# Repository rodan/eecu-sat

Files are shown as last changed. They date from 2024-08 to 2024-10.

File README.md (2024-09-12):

<a href="https://scan.coverity.com/projects/rodan-eecu-sat">
  
</a>

## eecu-sat (Engine ECU signal acquisition tool)

set of multiple modules that allow all analog signals generated and received by a vehicle's Engine Electronic Control Unit to be captured and analyzed. it can either be used as a testing jig for EECUs or as a low level diagnostic tool in which a known good set of signals can be used as reference.

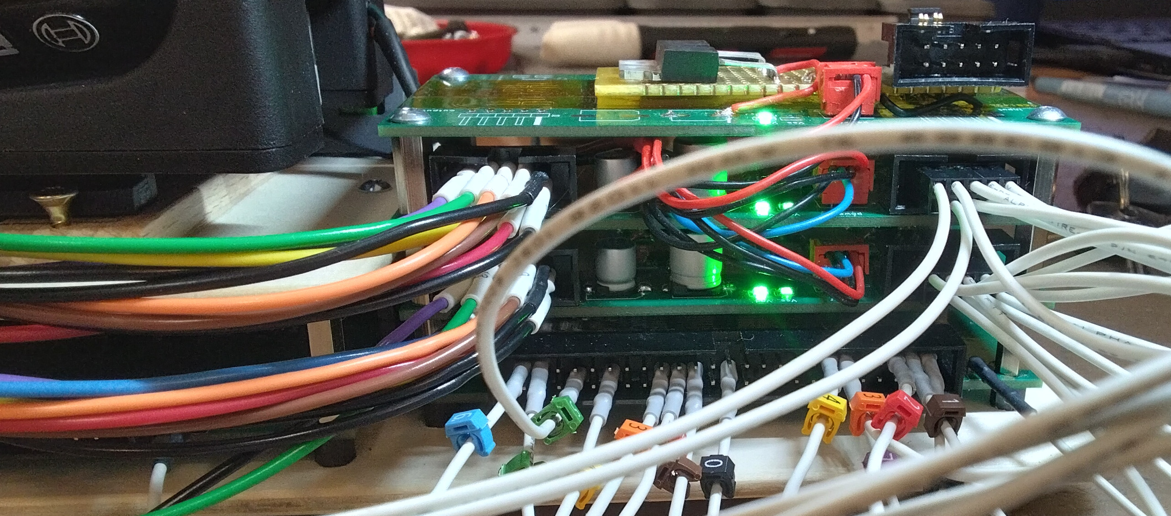
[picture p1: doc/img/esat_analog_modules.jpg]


a number of filters and buffers are used to protect the ADCs from transient spikes generated by all inductive loads

```
 source:       https://github.com/rodan/eecu-sat
 author:       Petre Rodan <2b4eda@subdimension.ro>
 license:      GNU GPLv3

 software architecture based on libsigrok and sigrok-cli
 source:       https://sigrok.org
 author:       Bert Vermeulen
 license:      GNU GPLv3
```

more images of the prototype in action are available [here](https://photos.app.goo.gl/Gay5FS8gsCTZkYcH9)

## Project components

project directory structure

 * ./hardware/buffy - kicad based schematics and pcbs for the analog buffer stage
 * ./hardware/pb\_jst-zro*  - kicad based schematics and pcbs for the proxy boards that intercept all EECU signals for a KTM 1090 EECU that uses JST ZRO 36 and 48 pin connectors
 * ./ltspice - spice simulation of the analog buffer schematic
 * ./software/eecu-sat - program that processes the raw analog data exported by [Saleae's Logic](https://www.saleae.com/pages/downloads) and converts them into [sigrok](https://sigrok.org/wiki/File_format:Sigrok/v2) files
 * .doc/ktm\_1090\_wiring.ods - ktm 1090 ECU pinout based on wire harness specs present in the service manual

## eecu-sat software

The software's code is shaped around the [sigrok](https://sigrok.org) library which is a great open-source signal analysis suite. I would have preferred to simply patch libsigrok and sigrok-cli to support the functionality that was needed for this project, however things did not go that smoothly. AFAICT libsigrok assumes that all input signals formats are interlaced, which makes sense from an acquisition system standpoint - samples are usually read by a single thread by switching channels in a loop. so CH1\_sample, CH2\_sample ... CH16\_sample, CH1\_sample, CH2\_sample ... in a row. Also it only supports single-file inputs. Quoting a libsigrok source file,

```
Saleae Logic applications typically export one file per channel. The sigrok
input modules exclusively handle an individual file, existing applications
may not be prepared to handle a set of files, or handle "special" file types
like directories. Some of them will even actively reject such input specs.
Merging multiple exported channels into either another input file or a sigrok
session is supposed to be done outside of this input module.
```

This is the reason why the code is basically a fork of sigrok-cli that contains my own input, output and transform modules that treat all samples in a non-interlaced manner.

### Build requirements

#### Linux
Notable dependencies would be a gcc, make, libzip and the libsigrok headers.

```
cd ./software/eecu-sat
make
```

#### FreeBSD

this is 'Work in progress', not functional just yet. dependencies: gcc13, gmake, gsed

```
export CC='/usr/local/bin/gcc13'
cd ./software/eecu-sat
gmake
```

### Usage

a manual is provided
```
man ./doc/eecu-sat.1
```

***SYNOPSIS***

eecu-sat [-hv] [-i, --input FILENAME_MATCH ] [-o, --output FILE\_PREFIX] [-O, --output-format OUTPUT ] [-t, --triggers TRIGGERS ] [-T, --transform-module TRANSFORM ] [-L, --list]

### TODO list (In Progress)

- [ ] analyze all 48 channels and automatically detect faults based on a known good reference capture
- [x] synchronize multiple sets of 16 channel acquisitions into one 48 channel srzip file
- [x] crop intervals in a signal, based on a trigger definition
- [x] convert Logic exported raw analog signals into srzip files that can be loaded in pulseview
- [x] relabeling capability of channels when seen in pulseview
- [x] 3-point calibration of all analog channels
  - [x] use ini file to input calibration paramenters
  - [x] analyze analog calibration signals, detect the calibration points
  - [x] apply acceptance criteria to input calibration signal
  - [x] export slopes and offsets into calibration ini file

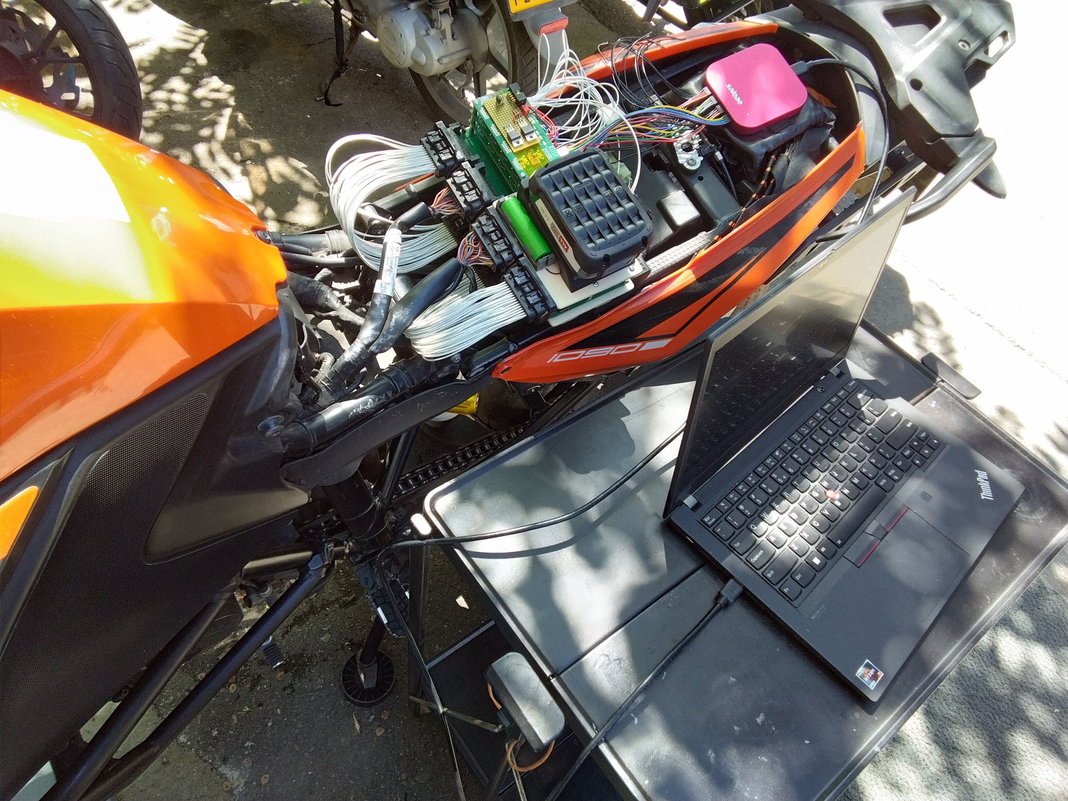
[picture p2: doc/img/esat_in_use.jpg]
tool in use


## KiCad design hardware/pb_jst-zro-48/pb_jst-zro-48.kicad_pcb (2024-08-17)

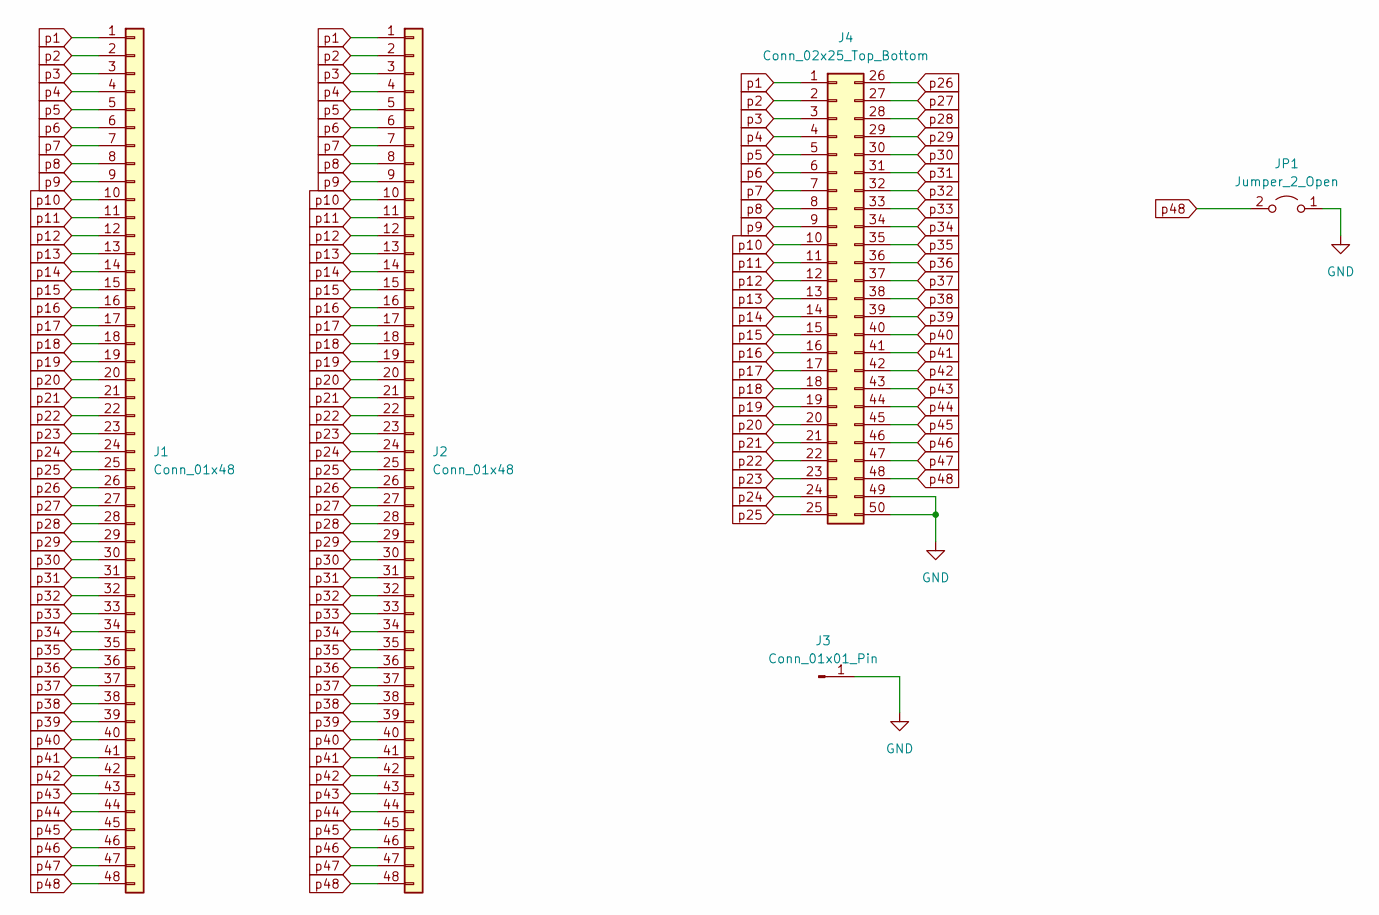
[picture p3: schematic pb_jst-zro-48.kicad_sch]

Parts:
J1, J2: Conn_01x48; S48B-ZROK-2A
J3: Conn_01x01_Pin; PinHeader_1x01_P2.54mm_Horizontal
J4: Conn_02x25_Top_Bottom; PinHeader_2x25_P2.54mm_Horizontal
JP1: Jumper_2_Open; PinHeader_1x02_P2.54mm_Vertical

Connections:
GND: J3.1, J4.49, J4.50, JP1.1 (A)
p1: J1.1, J2.1, J4.1
p2: J1.2, J2.2, J4.2
p3: J1.3, J2.3, J4.3
p4: J1.4, J2.4, J4.4
p5: J1.5, J2.5, J4.5
p6: J1.6, J2.6, J4.6
p7: J1.7, J2.7, J4.7
p8: J1.8, J2.8, J4.8
p9: J1.9, J2.9, J4.9
p10: J1.10, J2.10, J4.10
p11: J1.11, J2.11, J4.11
p12: J1.12, J2.12, J4.12
p13: J1.13, J2.13, J4.13
p14: J1.14, J2.14, J4.14
p15: J1.15, J2.15, J4.15
p16: J1.16, J2.16, J4.16
p17: J1.17, J2.17, J4.17
p18: J1.18, J2.18, J4.18
p19: J1.19, J2.19, J4.19
p20: J1.20, J2.20, J4.20
p21: J1.21, J2.21, J4.21
p22: J1.22, J2.22, J4.22
p23: J1.23, J2.23, J4.23
p24: J1.24, J2.24, J4.24
p25: J1.25, J2.25, J4.25
p26: J1.26, J2.26, J4.26
p27: J1.27, J2.27, J4.27
p28: J1.28, J2.28, J4.28
p29: J1.29, J2.29, J4.29
p30: J1.30, J2.30, J4.30
p31: J1.31, J2.31, J4.31
p32: J1.32, J2.32, J4.32
p33: J1.33, J2.33, J4.33
p34: J1.34, J2.34, J4.34
p35: J1.35, J2.35, J4.35
p36: J1.36, J2.36, J4.36
p37: J1.37, J2.37, J4.37
p38: J1.38, J2.38, J4.38
p39: J1.39, J2.39, J4.39
p40: J1.40, J2.40, J4.40
p41: J1.41, J2.41, J4.41
p42: J1.42, J2.42, J4.42
p43: J1.43, J2.43, J4.43
p44: J1.44, J2.44, J4.44
p45: J1.45, J2.45, J4.45
p46: J1.46, J2.46, J4.46
p47: J1.47, J2.47, J4.47
p48: J1.48, J2.48, J4.48, JP1.2 (B)

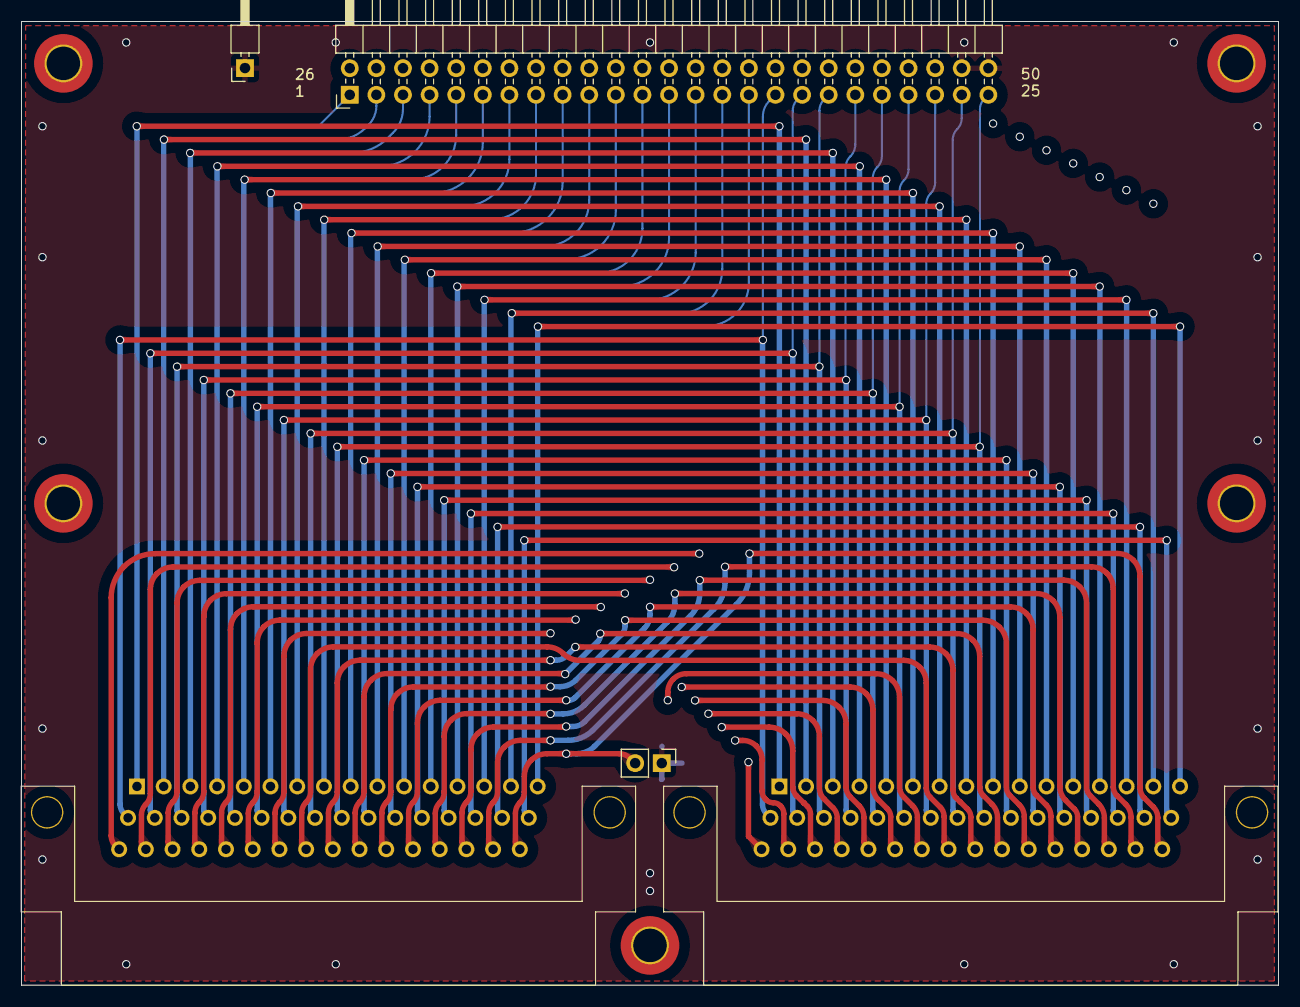
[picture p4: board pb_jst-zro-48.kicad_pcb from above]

Board: 4 copper layers, 120.0 x 92.0 mm, 5 parts (0 on the bottom side), 49 nets.

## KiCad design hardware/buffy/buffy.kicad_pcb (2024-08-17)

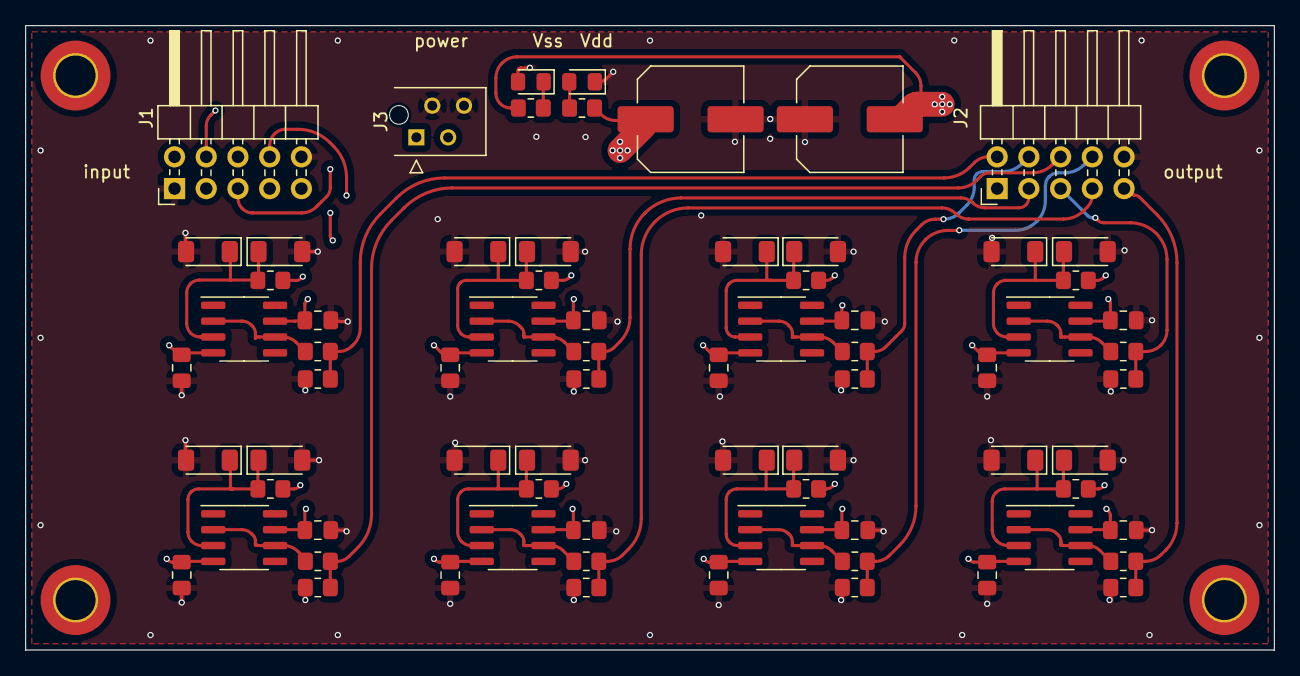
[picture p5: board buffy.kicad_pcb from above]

Board: 4 copper layers, 100.0 x 50.0 mm, 73 parts (0 on the bottom side), 37 nets.

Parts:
C1, C2: 220u; C_Elec_8x10.2
C102, C103, C112, C113, C122, C123, C132, C133, C142, C143, C152, C153, C162, C163, C172, C173: 100n; C_0805_2012Metric_Pad1.18x1.45mm_HandSolder
D1, D2: LED; LED_0805_2012Metric_Pad1.15x1.40mm_HandSolder
D101, D111, D121, D131, D141, D151, D161, D171: TZMB15-GS08; D_MiniMELF
D102, D112, D122, D132, D142, D152, D162, D172: BZV55B15; D_MiniMELF
J1, J2: Conn_02x05_Odd_Even; PinHeader_2x05_P2.54mm_Horizontal
J3: Conn_01x04_Pin; TE_Micro-MaTch_215079-4_2x02_P1.27mm_Vertical
R1, R2: 100k; R_0805_2012Metric_Pad1.20x1.40mm_HandSolder
R101, R111, R121, R131, R141, R151, R161, R171: 10K; R_0805_2012Metric_Pad1.20x1.40mm_HandSolder
R105, R115, R125, R135, R145, R155, R165, R175: 5K 0.1%; R_0805_2012Metric_Pad1.20x1.40mm_HandSolder
R106, R116, R126, R136, R146, R156, R166, R176: 10K 0.1%; R_0805_2012Metric_Pad1.20x1.40mm_HandSolder
U101, U111, U121, U131, U141, U151, U161, U171: OPA140; SOIC-8_3.9x4.9mm_P1.27mm

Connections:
GND: C1.2, C2.1, C102.2, C103.1, C112.2, C113.1, C122.2, C123.1, C132.2, C133.1, C142.2, C143.1, C152.2, C153.1, C162.2, C163.1, C172.2, C173.1, D1.1 (K), D2.2 (A), D101.2 (A), D102.2 (A), D111.2 (A), D112.2 (A), D121.2 (A), D122.2 (A), D131.2 (A), D132.2 (A), D141.2 (A), D142.2 (A), D151.2 (A), D152.2 (A), D161.2 (A), D162.2 (A), D171.2 (A), D172.2 (A), J1.1, J1.10, J2.1, J2.10, J3.2, J3.4, R106.2, R116.2, R126.2, R136.2, R146.2, R156.2, R166.2, R176.2
unnamed: D1.2 (A), R1.2
unnamed: D2.1 (K), R2.2
unnamed: D101.1 (K), D102.1 (K), R101.1, U101.3 (+)
unnamed: D111.1 (K), D112.1 (K), R111.1, U111.3 (+)
unnamed: D121.1 (K), D122.1 (K), R121.1, U121.3 (+)
unnamed: D131.1 (K), D132.1 (K), R131.1, U131.3 (+)
unnamed: D141.1 (K), D142.1 (K), R141.1, U141.3 (+)
unnamed: D151.1 (K), D152.1 (K), R151.1, U151.3 (+)
unnamed: D161.1 (K), D162.1 (K), R161.1, U161.3 (+)
unnamed: D171.1 (K), D172.1 (K), R171.1, U171.3 (+)
unnamed: R105.1, U101.2 (-), U101.6
unnamed: R115.1, U111.2 (-), U111.6
unnamed: R125.1, U121.2 (-), U121.6
unnamed: R135.1, U131.2 (-), U131.6
unnamed: R145.1, U141.2 (-), U141.6
unnamed: R155.1, U151.2 (-), U151.6
unnamed: R165.1, U161.2 (-), U161.6
unnamed: R175.1, U171.2 (-), U171.6
VDD: C1.1, C102.1, C112.1, C122.1, C132.1, C142.1, C152.1, C162.1, C172.1, J3.1, R1.1, U101.7 (V+), U111.7 (V+), U121.7 (V+), U131.7 (V+), U141.7 (V+), U151.7 (V+), U161.7 (V+), U171.7 (V+)
VSS: C2.2, C103.2, C113.2, C123.2, C133.2, C143.2, C153.2, C163.2, C173.2, J3.3, R2.1, U101.4 (V-), U111.4 (V-), U121.4 (V-), U131.4 (V-), U141.4 (V-), U151.4 (V-), U161.4 (V-), U171.4 (V-)
in0: J1.2, R101.2
in1: J1.3, R111.2
in2: J1.4, R121.2
in3: J1.5, R131.2
in4: J1.6, R141.2
in5: J1.7, R151.2
in6: J1.8, R161.2
in7: J1.9, R171.2
out0: J2.2, R105.2, R106.1
out1: J2.3, R115.2, R116.1
out2: J2.4, R125.2, R126.1
out3: J2.5, R135.2, R136.1
out4: J2.6, R145.2, R146.1
out5: J2.7, R155.2, R156.1
out6: J2.8, R165.2, R166.1
out7: J2.9, R175.2, R176.1

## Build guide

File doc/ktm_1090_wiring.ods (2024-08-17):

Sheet: A10 - central electronics control unit
CO/34 X1
1 | wh-bl | radiator fans
2 | bl-gr | rear right turn signal
3 | bl-gn | radiator fans
4 | or-bl | right signal switch
5 | gn-ye | break/tail light
6 | ye | license plate light
8 | bl-pu | stop signal switch
9 | pk-ye | front brake light switch
10 | bl | turn signal front right
11 | br | GND?
12 | bu-gr | connector, A11.26
13 | pu-or | left signal switch
14 | pu-gn | hazard switch
15 | rd-gr | horn switch
17 | pk-br | rear break light switch
18 | pu | turn signal front left
19 | br | GND?
20 | rd-pu | alarm system
22 | gn-pk | connector X100.1, 8.F1 o
23 | gn-gr | connector X100.7, 8.F1 p
25 | rd-gr | high beam switch
24 | gn | connector, A11.25
26 | bl-bu | fuel pump
27 | gr-pu | turn signal rear left
28 | bu-br | fuel pump
30 | wh-gn | break/tail light
31 | wh-rd | 12V?
33 | wh-rd | ACC2 12V out
A0/26 X2
1 | wh | parking light/daytime running light
3 | ye-rd | connector X100.8, A11.1/48
4 | gn-rd | q 5.F8
5 | or | evaporate emissions control valve
6 | lbu | tip switch
7 | gn | low beam
8 | bl-rd | starter relay 30A fuse 12V out
9 | bl-br | 6.F8 j, connector X100.6, 8.F1 j
10 | wh-bl | connector X100.12, A11.31/48
11 | or | evaporate emissions control valve
12 | wh-bu | CAN L, 5.B8 l, connector X100.10
13 | bl-bu | CAN H, 5.B8 h, connector X100.9
14 | gr | horn
15 | br-rd | fuel level sensor
16 | br-gn | connector X100.16, 8.F1 t
17 | wh-rd | voltage regulator 12V out
18 | rd | ignition/steering lock
19 | wh-rd | F2 10A fuse ACC1 12V out
20 | bu | high beam
21 | bl-br | combination switch common
22 | wh-ye | parking light/daytime running light
23 | wh-gr | emergency OFF
24 | br | GND?
25 | bl-ye | GND?
26 | ye-or | heated grip connector

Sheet: A11 - Engine electronics control unit
GF/48 |  |  | sequence | channel | aq channel
1 | ye-rd | connector X100.8, A10.3/26 | 1 | 0 | 0 0
2 | lbu | lambda sensor, cylinder 1 (heater) | 3 | 0 | 0 0
3 | or-pk | lambda sensor, cylinder 2 (heater) | 3 | 1 | 0 1
6 | bl-or | connector X100.15, evaporate emission control valve | 1 | 1 | 0 1
7 | wh-rd | SAS valve | 1 | 2 | 0 2
8 | br | GND
13 | br | GND
14 | wh-pu | ignition coil 1, cylinder 1 | 3 | 2 | 0 2
15 | wh-br | ignition coil 1, cylinder 2 | 3 | 3 | 0 3
16 | ye-pu | ignition coil 2, cylinder 1 | 3 | 4 | 0 4
17 | bu-pu | accelerator position sensor circuit A/B (bus) | 1 | 3 | 0 3
18 | bl | sensors common | 1 | 4 | 0 4
19 | bl-pk | tps? bus | 1 | 5 | 0 5
20 | ye-or | tps? | 1 | 6 | 0 6
21 | pu-gn | accelerator position sensor circuit A/B | 1 | 7 | 0 7
23 | br-gn | gear position sensor pin4 | 1 | 8 | 1 0
24 | wh | connector X100.3, 6.F8 i | 3 | 5 | 0 5
25 | gn | connector X100.5, A10.24/34 | 3 | 6 | 0 6
26 | wh-or | tps? | 1 | 9 | 1 1
27 | wh-gr | gear position sensor pin1 | 1 | 10 | 1 2
28 | gn-pk | accelerator position sensor circuit A/B | 1 | 11 | 1 3
31 | wh-bl | connector X100.12, A10.10/26 | 1 | 12 | 1 4
32 | ye-br | ignition coil 2, cylinder 2 | 3 | 7 | 0 7
33 | bu-pk | tps? bus | 1 | 13 | 1 5
34 | bu | sensors common | 2 | 0 | 0 0
35 | bl-pu | accelerator position sensor circuit A/B (bus) | 2 | 1 | 0 1
36 | pu | induction manifold pressure sensor cylinder 1 | 3 | 8 | 1 0
37 | gr-pu | induction manifold pressure sensor cylinder 2 | 3 | 9 | 1 1
38 | ye-gn | rollover sensor | 2 | 2 | 0 2
40 | bl-ye | coolant temperature sensor cylinder 1 | 2 | 3 | 0 3
41 | gn-gr | ambient air pressure sensor | 2 | 4 | 0 4
42 | rd | intake air temperature sensor | 2 | 5 | 0 5
45 | ye | connector X100.11, clutch switch | 2 | 6 | 0 6
47 | pk | side stand sensor | 2 | 7 | 0 7
48 | br | GND
GG/36 | jst k-d
1 | or | connector X100.4 X100.14, A10.5/26 A10.11/26 | 2 | 8 | 1 0
2 | gn-or | throttle stepper motor pin 2 | 2 | 9 | 1 1
3 | bu-gn | throttle stepper motor pin 1 | 3 | 10 | 1 2
10 | bl-gr | injection valve cylinder 1 | 3 | 11 | 1 3
11 | br-gr | injection valve cylinder 2 | 3 | 12 | 1 4
13 | or | connector X100.4 X100.14, A10.5/26 A10.11/26 | 2 | 10 | 1 2
20 | br-pu | connector X100.13, clutch switch, GND | 2 | 11 | 1 3
21 | gn-rd | lambda sensor, cylinder 1 (sensor - offset from gnd) | 2 | 12 | 1 4
22 | br-rd | lambda sensor, cylinder 2 (sensor - offset from gnd) | 2 | 13 | 1 5
23 | GND
25 | GND
26 | bu-gr | connector X100.2, A10.12/34 | 2 | 14 | 1 6
33 | bl-bu | connector X100.9, CAN H | 3 | 13 | 1 5
34 | wh-bu | connector X100.10, CAN L | 3 | 14 | 1 6
35 | ye-bu | crankshaft position sensor | 2 | 15 | 1 7
36 | wh-ye | crankshaft position sensor | 3 | 15 | 1 7

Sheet: P10 - combination instrument
1 | bl-ye | a 3.F8, alarm system
2 | bu-br | common (up/down/set/return) switches GND?
3 | gn-rd | q 5.F1
4 | bu-rd | e 3.E8, alarm system A50.11
5 | bl-bu | CAN H
6 | wh-bu | CAN L
7 | gr-pu | switch (return)
8 | ye-gr | switch (set)
9 | gr-or | switch (down)
10 | gn-gr | switch (up)
11 | wh | i 6.F1
12 | gr | air temperature sensor

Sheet: A30 - ABS control unit
1 | bl | GND
2 | bl-bu | CAN H
3 | bl-gr | front wheel speed sensor
4 | gn-rd | q 4.F8
5 | lbu | diagnostic connector
9 | rd | fuse 15A F21
10 | bl | GND
11 | wh-bl | CAN L
12 | gr | front wheel speed sensor
13 | wh | rear wheel speed sensor
14 | wh-bl | rear wheel speed sensor
18 | or | fuse 25A F22

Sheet: A50 - alarm system unit
4 | bu | alarm system switch (optional)
6 | br | GND?
7 | gn | antenna?
8 | bl-ye | P10.1
9 | rd-pu | A10.20
11 | bu-rd | P10.4
14 | rd | 3.F8 f 12V?

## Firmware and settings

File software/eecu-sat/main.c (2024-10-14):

/*
 * This file is part of the eecu-sat project.
 *
 * Copyright (C) 2024 Petre Rodan <2b4eda@subdimension.ro>
 *
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
 * You should have received a copy of the GNU General Public License
 * along with this program.  If not, see <http://www.gnu.org/licenses/>.
 */

// program that converts a number of raw analog capture files generated by saleae's logic into a srzip file recognized by sigrok

#define _GNU_SOURCE
#include <stdlib.h>
#include <stdio.h>
#include <stdint.h>
#include <stdbool.h>
#include <getopt.h>
#include <dirent.h>
#include <fnmatch.h>
#include <libgen.h>
#include <string.h>
#include <unistd.h>
#include <sys/stat.h>
#include <fcntl.h>

#include "config.h"
#include "error.h"
#include "proj.h"
#include "version.h"
#include "saleae.h"
#include "output.h"
#include "output_analog.h"
#include "output_srzip.h"
#include "transform.h"
#include "calib.h"
#include "parsers.h"
#include "trigger.h"
#include "session.h"
#include "strnatcmp.h"

// program arguments
static char *opt_default_input_prefix = "analog_[0-9]*.bin";
struct cmdline_opt opt = { 0 };

static void show_usage(void)
{
    fprintf(stdout, "Usage: eecu-sat [-i PREFIX] [-o FILE]\n");
    fprintf(stdout, "\t-i, --input\n");
    fprintf(stdout, "\t\ta prefix that defines the input files. default is %s\n", opt_default_input_prefix);
    fprintf(stdout, "\t-I, --input-format\n");
    fprintf(stdout, "\t\tinput data format to use, see -L for list\n");
    fprintf(stdout, "\t-o, --output=FILE\n");
    fprintf(stdout, "\t\toutput file to be generated\n");
    fprintf(stdout, "\t-O, --output-format OUTPUT\n");
    fprintf(stdout, "\t\toutput data format to use, see -L for list\n");
    fprintf(stdout, "\t-t, --triggers TRIGGERS\n");
    fprintf(stdout, "\t\ttrigger configuration\n");
    fprintf(stdout, "\t-T, --transform-module TRANSFORM\n");
    fprintf(stdout, "\t\tprocess data via a function, see -L for list\n");
    fprintf(stdout, "\t-L, --list\n");
    fprintf(stdout, "\t\tlist known output formats and transform modules\n");
    fprintf(stdout, "\t-h, --help\n");
    fprintf(stdout, "\t-v, --version\n");
}

static void show_version(void)
{
    fprintf(stdout, "eecu-sat version: %d.%d build %d commit %d\n", VER_MAJOR, VER_MINOR, BUILD, COMMIT);
}

static void show_capabilities(void)
{
    const struct sr_output_module **outputs;
    const struct sr_transform_module **transforms;
    int i;

    printf("Supported output formats:\n");
    outputs = sat_output_list();
    for (i = 0; outputs[i]; i++) {
        printf("  %-20s %s\n", sat_output_id_get(outputs[i]), sat_output_description_get(outputs[i]));
    }

    printf("Supported transform modules:\n");
    transforms = sat_transform_list();
    for (i = 0; transforms[i]; i++) {
        printf("  %-20s %s\n", sat_transform_id_get(transforms[i]), sat_transform_description_get(transforms[i]));
    }

}

static int parse_options(int argc, char **argv)
{
    int q, opt_idx;

    while (1) {
        opt_idx = 0;
        static struct option long_options[] = {
            {"input", 1, 0, 'i'},
            {"input-format", 1, 0, 'I'},
            {"output", 1, 0, 'o'},
            {"output-format", 1, 0, 'O'},
            {"triggers", 1, 0, 't'},
            {"transform-module", 1, 0, 'T'},
            {"list", 0, 0, 'L'},
            {"help", 0, 0, 'h'},
            {"version", 0, 0, 'v'},
            {0, 0, 0, 0}
        };

        q = getopt_long(argc, argv, "i:I:o:O:t:T:Lhv", long_options, &opt_idx);
        if (q == -1) {
            break;
        }
        switch (q) {
        case 'i':
            opt.input_prefix = optarg;
            break;
        case 'I':
            opt.input_format = optarg;
            break;
        case 'o':
            opt.output_file = optarg;
            break;
        case 'O':
            opt.output_format = optarg;
            break;
        case 't':
            opt.triggers = optarg;
            break;
        case 'T':
            opt.transform_module = optarg;
            break;
        case 'L':
            show_capabilities();
            break;
        case 'h':
            show_usage();
            break;
        case 'v':
            show_version();
            break;
        default:
            break;
        }
    }

    if (!opt.input_prefix) {
        opt.input_prefix = opt_default_input_prefix;
    }

    return SR_OK;
}

static void logger(const gchar *log_domain, GLogLevelFlags log_level,
           const gchar *message, gpointer cb_data)
{
    (void)log_domain;
    (void)cb_data;

    /*
     * All messages, warnings, errors etc. go to stderr (not stdout) in
     * order to not mess up the CLI tool data output, e.g. VCD output.
     */
    if (log_level & (G_LOG_LEVEL_ERROR | G_LOG_LEVEL_CRITICAL | G_LOG_LEVEL_WARNING)
            || opt.loglevel > SR_LOG_WARN) {
        fprintf(stderr, "%s\n", message);
        fflush(stderr);
    }

    //if (log_level & (G_LOG_LEVEL_ERROR | G_LOG_LEVEL_CRITICAL))
    //    exit(1);
}

static int cmp_channel_names(const void *leftp, const void *rightp)
{
    const ch_data_t *left = leftp;
    const ch_data_t *right = rightp;
    return strnatcmp(left->input_file_name, right->input_file_name);
}

int main(int argc, char **argv)
{
    int res;
    struct dirent **namelist;
    int i, ch_cnt = 0;
    int channel_total = 0;
    char *_input_dirname = NULL;
    char *input_dirname;
    char *_input_basename = NULL;
    char *input_basename;
    ssize_t file_name_len;
    FILE *fp;
    ch_data_t *ch_data_ptr;
    ssize_t file_size_compare = -1;
    int ret = SR_OK;
    struct sr_dev_inst sdi = { 0 };
    struct dev_frame frame = { 0 };
    GSList *l, *channels = NULL;
    uint8_t buff[SALEAE_ANALOG_HDR_SIZE];

    opt.loglevel = SR_LOG_INFO;
    g_log_set_default_handler(logger, NULL);

    if (parse_options(argc, argv)) {
        return SR_ERR_ARG;
    }

    if (sr_log_loglevel_set(opt.loglevel) != SR_OK)
        return SR_ERR_ARG;

    _input_dirname = strdup(opt.input_prefix);
    _input_basename = strdup(opt.input_prefix);

    input_dirname = dirname(_input_dirname);
    input_basename = basename(_input_basename);

    //printf("input files prefix is %s, dirname %s, basename %s\n", opt.input_prefix, input_dirname, input_basename);
    ch_cnt = scandir(input_dirname, &namelist, NULL, versionsort);

    sdi.priv = &frame;

    // create a linked list with all files that match the filter defined by the --input option
    if (ch_cnt < 0)
        perror("scandir");
    else {
        for (i = 0; i < ch_cnt; i++) {
            // non GNU libc implementations lack the FNM_EXTMATCH flag, so the natural sorting of the filenames needs to happen separately
            res = fnmatch(input_basename, namelist[i]->d_name, 0);
            if (!res) {
                //printf("%s matches\n", namelist[i]->d_name);
                channel_total++;
                ch_data_ptr = g_malloc0(sizeof(struct ch_data));

                file_name_len = strlen(input_dirname) + strlen(namelist[i]->d_name);
                ch_data_ptr->input_file_name = (char *)g_malloc0((file_name_len + 3) * sizeof(char));
                snprintf(ch_data_ptr->input_file_name, file_name_len + 2, "%s/%s", input_dirname, namelist[i]->d_name);
                ch_data_ptr->sample_size = sizeof(float);

                // get file size
                if ((fp = fopen(ch_data_ptr->input_file_name, "r")) == NULL) {
                    err_msg("%s:%d opening input file", __FILE__, __LINE__);
                    g_free(ch_data_ptr->input_file_name);
                    g_free(ch_data_ptr);
                    ret = SR_ERR_ARG;
                    goto cleanup;
                }
                fseek(fp, 0L, SEEK_END);
                ch_data_ptr->input_file_size = ftell(fp);

                fseek(fp, 0L, SEEK_SET);
                if (fread(&buff, 1, SALEAE_ANALOG_HDR_SIZE, fp) != SALEAE_ANALOG_HDR_SIZE) {
                    err_msg("%s:%d during fread()", __FILE__, __LINE__);
                    g_free(ch_data_ptr->input_file_name);
                    g_free(ch_data_ptr);
                    fclose(fp);
                    ret = SR_ERR_IO;
                    goto cleanup;
                }

                ch_data_ptr->file_type = saleae_get_hdr_type(&buff[0]);

                if (ch_data_ptr->file_type == SALEAE_ANALOG) {
                    ch_data_ptr->sample_count = (ch_data_ptr->input_file_size - SALEAE_ANALOG_HDR_SIZE) / ch_data_ptr->sample_size;
                    memcpy(&ch_data_ptr->header, buff, SALEAE_ANALOG_HDR_SIZE);
#if 0
                    fprintf(stdout, "channel %s\n", ch_data_ptr->input_file_name);
                    fprintf(stdout, "  version %d\n", ch_data_ptr->header.version);
                    fprintf(stdout, "  type %d\n", ch_data_ptr->header.type);
                    fprintf(stdout, "  begin time %lf\n", ch_data_ptr->header.begin_time);
                    fprintf(stdout, "  sample rate %ld\n", ch_data_ptr->header.sample_rate);
                    fprintf(stdout, "  downsample %ld\n", ch_data_ptr->header.downsample);
                    fprintf(stdout, "  sample cnt %ld %ld\n", ch_data_ptr->header.num_samples, ch_data_ptr->sample_count);
#endif
                } else if (ch_data_ptr->file_type == SALEAE_DIGITAL) {
                    err_msg("%s:%d cannot use digital input files", __FILE__, __LINE__);
                    g_free(ch_data_ptr->input_file_name);
                    g_free(ch_data_ptr);
                    fclose(fp);
                    ret = SR_ERR_ARG;
                    goto cleanup;
                } else {
                    ch_data_ptr->sample_count = ch_data_ptr->input_file_size / ch_data_ptr->sample_size;
                }
 
                fclose(fp);

                if (file_size_compare == -1)
                    file_size_compare = ch_data_ptr->input_file_size;
                if (file_size_compare != ch_data_ptr->input_file_size) {
                    err_msg("%s:%d file %s has %ld bytes, but %ld bytes were expected", __FILE__, __LINE__, ch_data_ptr->input_file_name,
                            ch_data_ptr->input_file_size, file_size_compare);
                    g_free(ch_data_ptr->input_file_name);
                    g_free(ch_data_ptr);
                    ret = SR_ERR_ARG;
                    goto cleanup;
                }
                sdi.channels = g_slist_append(sdi.channels, ch_data_ptr);
            }
        }
    }

    // sort list using a natural sort algorithm
    sdi.channels = g_slist_sort(sdi.channels, cmp_channel_names);

    // set channel ids on the sorted list
    channel_total = 1;
    channels = sr_dev_inst_channels_get(&sdi);
    for (l = channels; l; l = l->next) {
        ch_data_ptr = l->data;
        ch_data_ptr->id = channel_total;
        channel_total++;
        //fprintf(stdout, "file id %d in list %s\n", ch_data_ptr->id, ch_data_ptr->input_file_name);
    }

    if (channel_total) {
        ret = run_session(&sdi, &opt);
    } else {
        err_msg("%s:%d no valid input channels found", __FILE__, __LINE__);
        show_usage();
        ret = SR_ERR_ARG;
        goto cleanup;
    }

cleanup:
    for (i = 0; i < ch_cnt; i++) {
        free(namelist[i]);
    }
    free(namelist);
    channels = sr_dev_inst_channels_get(&sdi);
    if (channels) {
        for (l = channels; l; l = l->next) {
            ch_data_ptr = l->data;
            if (ch_data_ptr->input_file_name)
                g_free(ch_data_ptr->input_file_name);
            if (ch_data_ptr->trigger)
                sat_trigger_free(ch_data_ptr->trigger);
            g_free(l->data);
        }
        g_slist_free(channels);
    }
    free(_input_dirname);
    free(_input_basename);

    return ret;
}

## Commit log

2024-08-17 initial import
    [buffy.kicad_pcb, buffy.kicad_sch, ch0.kicad_sch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]
2024-08-20 switch to using linked list library from the contiki-ng project
2024-08-21 parse calibration parameter file
2024-08-21 fix fd resource leak in case lseek fails
    [main.c]
2024-08-26 testing calibration
2024-08-27 use sdi->channels instead of a global variable, use sdi->priv to store current channel and chunk info
2024-09-01 add sample signals used by unit tests
2024-09-02 use libsigrok-style error levels
    [main.c]
2024-09-08 output_srzip: create metadata from scratch if not provided, calculate samplerate based on input headers
2024-09-09 unit_testing: update metadata inside sample_files archive
2024-09-12 use err_msg for all error reporting
    [main.c]
2024-10-14 fix run_session / prepare id order
    [main.c]

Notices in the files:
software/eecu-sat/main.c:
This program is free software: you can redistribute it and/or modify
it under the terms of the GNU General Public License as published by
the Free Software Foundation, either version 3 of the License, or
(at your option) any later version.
